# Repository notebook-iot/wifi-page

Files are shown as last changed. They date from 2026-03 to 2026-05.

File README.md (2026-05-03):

# wifi-page
WiFi enabled sidecar board enabling embedded devices to communicate with the cloud

## Known Issues in v1r1

- If you aren't careful when scratching the trace to switch the power path, there could be backfeed. We experienced the LDO drawing too much current despite the other pins being bridged, and the voltage on the power rail dropped to ~1V.
- There is no pull-down resistor on IO46, which is one of the strapping pins for flashing over UART using the joint download mode. We fixed this temporarily by tacking a wire between IO46 and GND.

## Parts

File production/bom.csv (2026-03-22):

Designator | Footprint | Quantity | Value | LCSC Part #
C1 | 0805 | 1 | 22u
C2, C3, C5 | 0805 | 3 | 0.1u
C4, C6, C7 | 0805 | 3 | 1u
D1 | 0805 | 1 | GREEN
D2, D3, D4 | D_SOD-323 | 3 | D_TVS
J1 | USB_Micro-AB_Molex_47590-0001 | 1 | USB_B_Micro
J2 | PinSocket_1x04_P2.54mm_Vertical | 1 | Conn_01x04
R1, R10, R3, R4, R8, R9 | 0805 | 6 | 0
R11, R12, R2, R5, R6, R7 | 0805 | 6 | 10k
R13 | 0805 | 1 | 470
SW1, SW2 | SW_Push_1P1T_NO_CK_KMR2 | 2 | SW_Push
TP1, TP2, TP3 | TestPoint_THTPad_D1.5mm_Drill0.7mm | 3 | TestPoint
U1 | ESP32-S3-WROOM-1 | 1 | ESP32-S3-WROOM-1
U2 | SOT-23-5 | 1 | AP2112K-3.3
U3 | SOIC-8_3.9x4.9mm_P1.27mm | 1 | CAT24C256

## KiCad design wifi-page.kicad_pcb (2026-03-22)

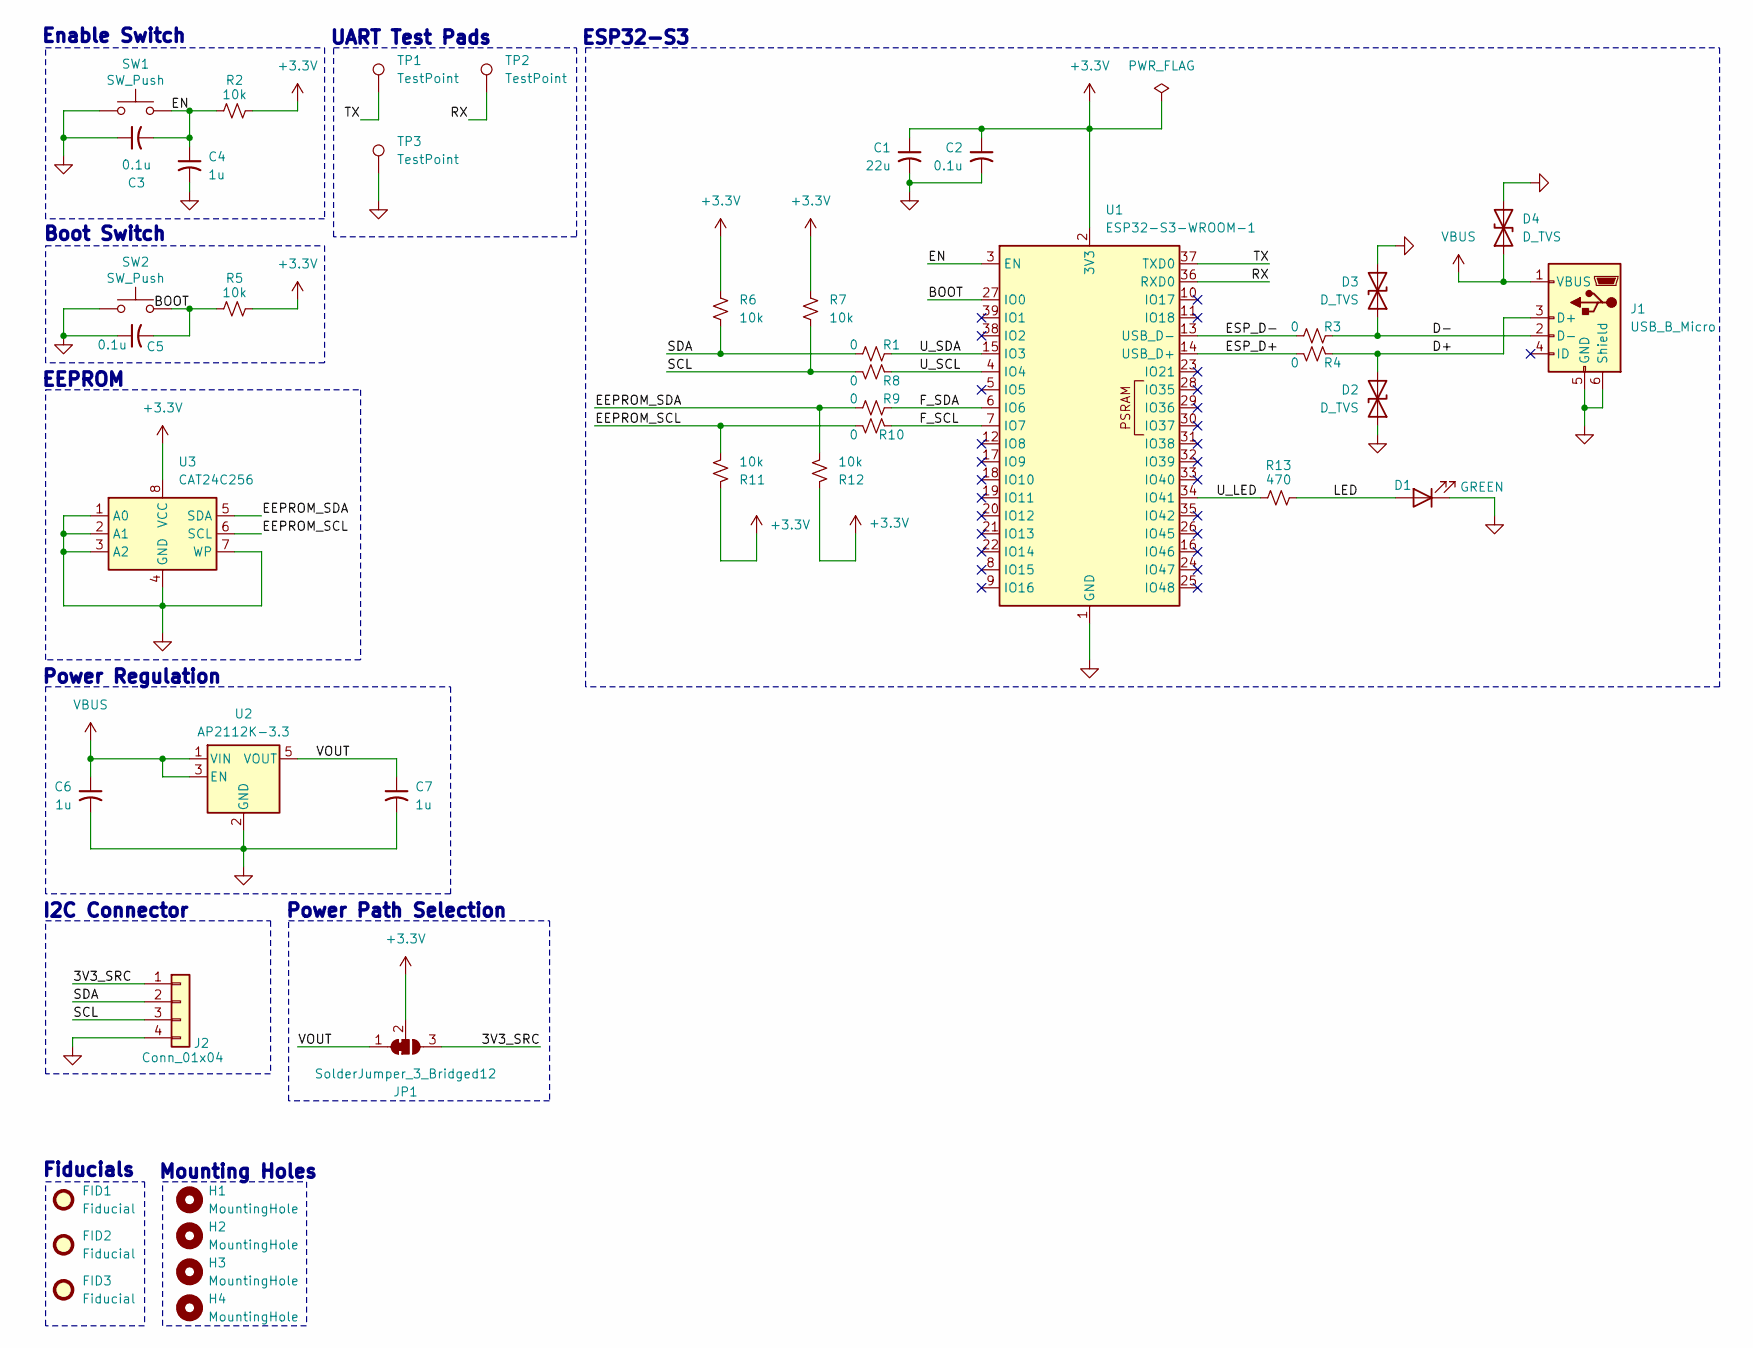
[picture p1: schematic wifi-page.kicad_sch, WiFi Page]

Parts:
C1: 22u; C_0805_2012Metric
C2, C3, C5: 0.1u; C_0805_2012Metric
C4, C6, C7: 1u; C_0805_2012Metric
D1: GREEN; LED_0805_2012Metric
D2, D3, D4: D_TVS; D_SOD-323
FID1, FID2, FID3: Fiducial; Fiducial_1mm_Mask2mm
H1, H2, H3, H4: MountingHole; MountingHole_2mm
J1: USB_B_Micro; USB_Micro-AB_Molex_47590-0001
J2: Conn_01x04; PinSocket_1x04_P2.54mm_Vertical
JP1: SolderJumper_3_Bridged12; SolderJumper-3_P1.3mm_Bridged12_RoundedPad1.0x1.5mm_NumberL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
R1, R3, R4, R8, R9, R10: 0; R_0805_2012Metric
R2, R5, R6, R7, R11, R12: 10k; R_0805_2012Metric
R13: 470; R_0805_2012Metric
SW1, SW2: SW_Push; SW_Push_1P1T_NO_CK_KMR2
TP1, TP2, TP3: TestPoint; TestPoint_THTPad_D1.5mm_Drill0.7mm
U1: ESP32-S3-WROOM-1
U2: AP2112K-3.3; SOT-23-5
U3: CAT24C256; SOIC-8_3.9x4.9mm_P1.27mm

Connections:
+3.3V: C1.1, C2.1, JP1.2 (C), R2.2, R5.2, R6.1, R7.1, R11.1, R12.1, U1.2 (3V3), U3.8 (VCC)
/3V3_SRC: J2.1, JP1.3 (B)
/BOOT: C5.2, R5.1, SW2.2, U1.27 (IO0)
/D+: D2.2 (A2), J1.3 (D+), R4.2
/D-: D3.1 (A1), J1.2 (D-), R3.2
/EEPROM_SCL: R10.1, R11.2, U3.6 (SCL)
/EEPROM_SDA: R9.1, R12.2, U3.5 (SDA)
/EN: C3.2, C4.1, R2.1, SW1.2, U1.3 (EN)
/ESP_D+: R4.1, U1.14 (USB_D+)
/ESP_D-: R3.1, U1.13 (USB_D-)
/F_SCL: R10.2, U1.7 (IO7)
/F_SDA: R9.2, U1.6 (IO6)
/LED: D1.2 (A), R13.2
/RX: TP2.1, U1.36 (RXD0)
/SCL: J2.3, R7.2, R8.1
/SDA: J2.2, R1.1, R6.2
/TX: TP1.1, U1.37 (TXD0)
/U_LED: R13.1, U1.34 (IO41)
/U_SCL: R8.2, U1.4 (IO4)
/U_SDA: R1.2, U1.15 (IO3)
/VOUT: C7.1, JP1.1 (A), U2.5 (VOUT)
GND: C1.2, C2.2, C3.1, C4.2, C5.1, C6.2, C7.2, D1.1 (K), D2.1 (A1), D3.2 (A2), D4.2 (A2), J1.5 (GND), J1.6 (Shield), J2.4, SW1.1, SW2.1, TP3.1, U1.1 (GND), U1.40 (GND), U1.41 (GND), U2.2 (GND), U3.1 (A0), U3.2 (A1), U3.3 (A2), U3.4 (GND), U3.7 (WP)
VBUS: C6.1, D4.1 (A1), J1.1 (VBUS), U2.1 (VIN), U2.3 (EN)

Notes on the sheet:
I2C Connector
Mounting Holes
EEPROM
Power Regulation
Enable Switch
Power Path Selection
UART Test Pads
ESP32-S3
Fiducials
Boot Switch

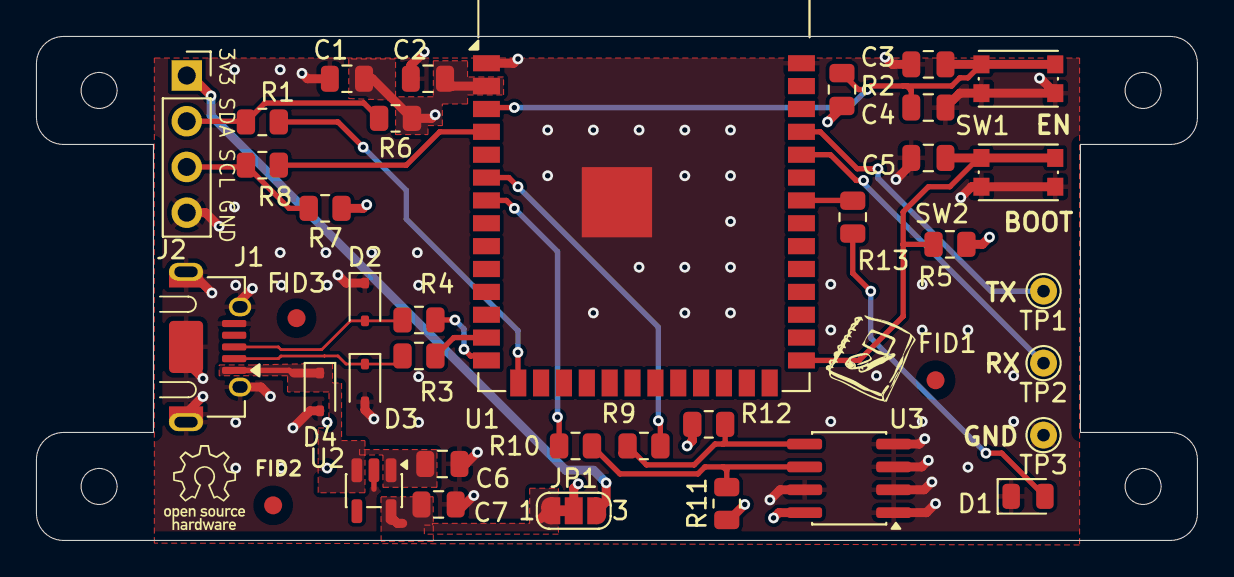
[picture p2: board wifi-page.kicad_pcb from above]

Board: 4 copper layers, 64.5 x 28.0 mm, 42 parts (0 on the bottom side), 23 nets.

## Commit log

2026-03-22 add initial revision
    [bom.csv, designators.csv, positions.csv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]
2026-03-22 update silkscreen
    [positions.csv, wifi-page.kicad_pcb]
